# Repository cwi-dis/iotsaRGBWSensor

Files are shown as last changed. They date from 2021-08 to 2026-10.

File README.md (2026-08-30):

# iotsaRGBWSensor




Light sensor that detects RGB, White and ambient light using a VEML6040 color sensor.

Based on [iotsa](https://github.com/cwi-dis/iotsa).

The sensor uses a cheap AliExpress VEML6040 board (you may have to de-solder the white LED if
you want to take emitted/ambient light readings, as opposed to measuring the color of objects).

The VEML6040 is described in <https://www.vishay.com/docs/84276/veml6040.pdf> with additional
design information available at <https://www.vishay.com/docs/84331/designingveml6040.pdf>.

The interface library used is <https://github.com/thewknd/VEML6040>

## Hardware construction

Any esp32 board will do. I have used a lolin 32 lite, because it has a LiPo charger on the board. Here is the breadboard layout:

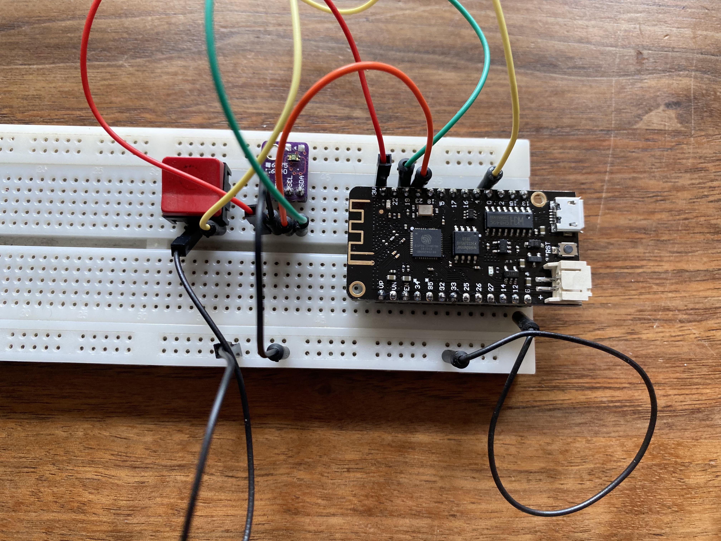
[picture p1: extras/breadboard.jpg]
breadboard layout


Connections to be made:

- GND to VEML GND, pushbutton
- 3V to VEML VCC
- GPIO19 to VEML SDA
- GPIO23 to VEML SCL
- GPIO0 to pushbutton

After the breadboard work I've transferred the components to a solderboard. It's not a work of art, I wanted the sensor on the bottom of the board for easier measurement, but that led to routing problems. But it works:

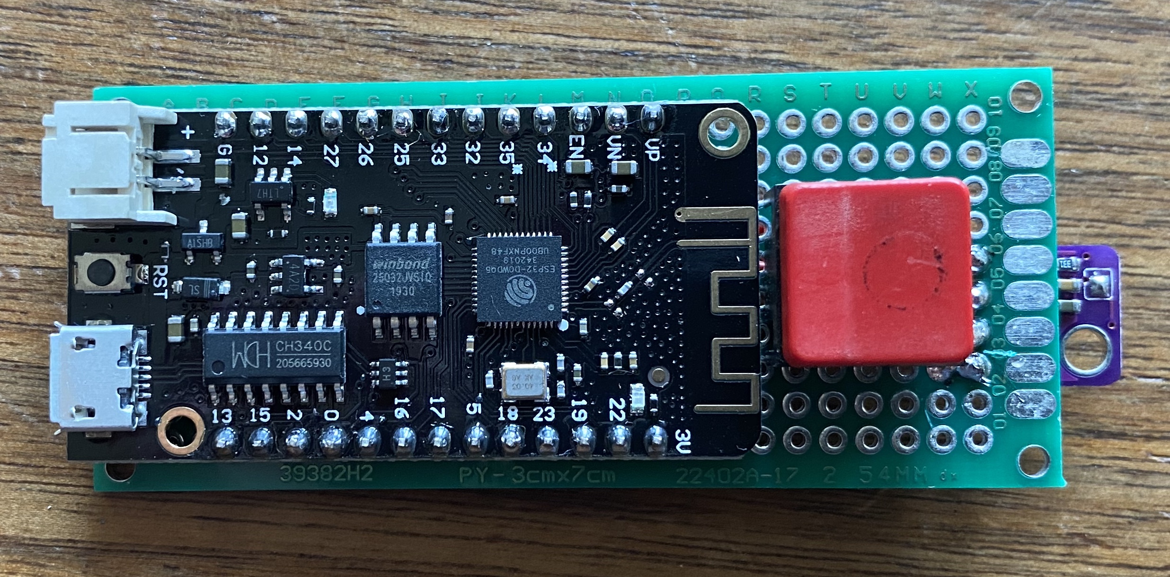
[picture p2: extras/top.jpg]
solderboard top


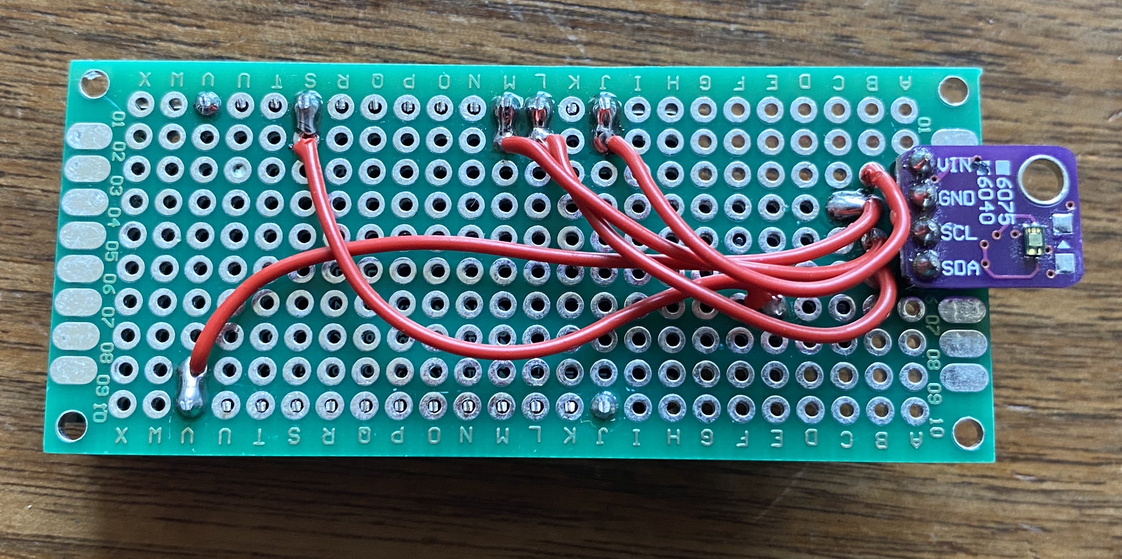
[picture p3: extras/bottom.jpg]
solderboard bottom


See the note above about desoldering the bright white LED on the VEML.

### 3d-printed case

Here are pictures of a 3d-printed case for the board, plus a LiPo battery:

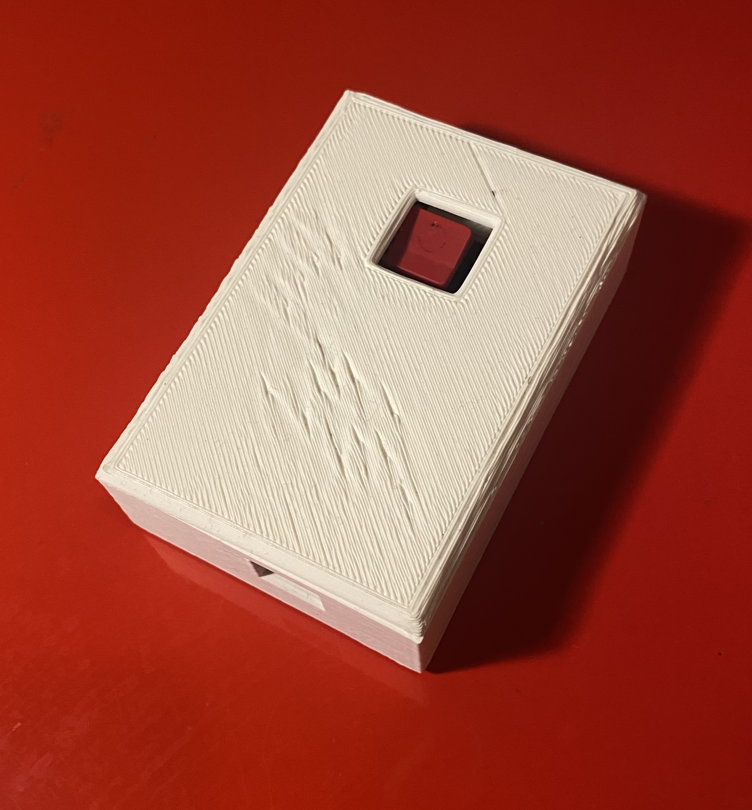
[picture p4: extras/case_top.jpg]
case top


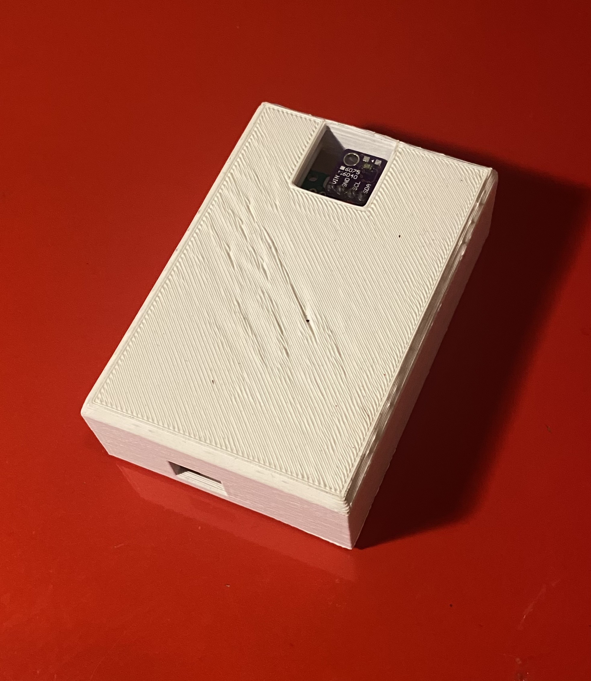
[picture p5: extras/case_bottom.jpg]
case bottom


The `extras` folder contains the `.stl` files to print the box and the lid, and it also has the `colorimeter.f3d` Autodesk Fusion file in case you want to make modifications.

## Software installation

- Build using PlatformIO (`pio run`), or the Arduino IDE / `arduino-cli`.
  - The `build_opt.h` file passes `-DIOTSA_WITH_BLE` to the Arduino build (PlatformIO
    gets it from `platformio.ini`). Don't remove it.
  - In the Arduino IDE, set **Tools → Partition Scheme → Minimal SPIFFS** — the
    BLE firmware does not fit the default partition.
  - Install the required libraries: `VEML6040`, plus everything in iotsa's
    `library.properties` `depends=` (`Adafruit NeoPixel`, `ArduinoJson`,
    `cmArduinoJWT`, `CoAP simple library`, `Ds1302`, `ESP32Encoder`,
    `NimBLE-Arduino`, `esp32_idf5_https_server_compat`). PlatformIO resolves
    these automatically; the Arduino IDE does not when iotsa is a local checkout.
- Flash to the board over USB.
- Board will create a WiFi hotspot `config-xxxxxxx`.
- Connect to that WiFi, browse to <http://192.168.4.1>, configure hostname (lets say `colorsensor` for this example), WiFi SSID and Password. You may have to reset the board to switch to configuration mode, it will tell you.
- Reset the board, it will connect to your wifi with hostname `colorsensor.local`.
- Browse to battery config. Set sleep mode to _Deep Sleep_, wake time to _60000_.

## Usage

Boot the board. If you have set the battery config above the board will go to deep sleep after 60 seconds of inactivity (saving battery). Pressing the button will wake it again, or keep it awake for another 60 seconds. Accessing the web or REST interface will also keep it awake for another 60 seconds.

Point the sensor at whatever light (or lit surface) you want to measure.

Read the results with a browser to <http://colorsensor.local/rgbw> in human-readable form, or <http://colorsensor.local/api/rgbw> as JSON (REST interface).

You can reflash the board over the air, see [iotsa](https://github.com/cwi-dis/iotsa) for details. Tapping the button 3 times will enable OTA mode or config mode (after being requested over the net), tapping it 6 times will force a reboot.

## Python tool

The `extras/python/` directory contains the `colorMeter` Python tool for retrieving, storing, and graphing readings from the device.

### Setup

(If instructions in this repo's parent directory cover venv setup, those take precedence over the steps below.)

From the repo root:

```sh
python3 -m venv .venv
source .venv/bin/activate
pip install -e ../iotsa/extras/python/
pip install -e extras/python/
```

Or, if you have the `requirements_dev.txt`:

```sh
python3 -m venv .venv
source .venv/bin/activate
pip install -r extras/python/requirements_dev.txt
pip install -e extras/python/
```

### Usage

Retrieve current data from a device and print it:

```sh
colorMeter -d colorsensor.local
```

Save readings to a CSV file (repeat to append more readings over time):

```sh
colorMeter -d colorsensor.local -o readings.csv
```

Read back a CSV file and plot the CCT (color temperature) reading on the CIE 1931 chromaticity diagram:

```sh
colorMeter -i readings.csv -g
```

This device is also used by [lissabon](https://github.com/cwi-dis/lissabon)'s `lissabonCalibrate` package to calibrate RGBW ledstrips (it talks to the device's `rgbw` API directly rather than through this tool). `colorMeter` is deliberately kept simpler and free of any lissabon-specific logic, so it stays useful as a general-purpose way to read this sensor — that was already the intent when it was split off in 2021.

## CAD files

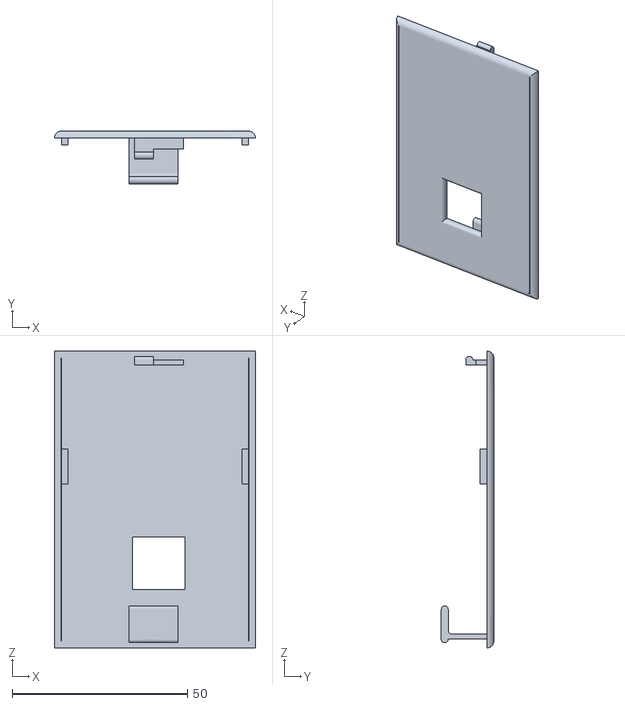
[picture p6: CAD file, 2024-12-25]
extras/colormeter_lid.stl
57.3 x 15.0 x 84.6

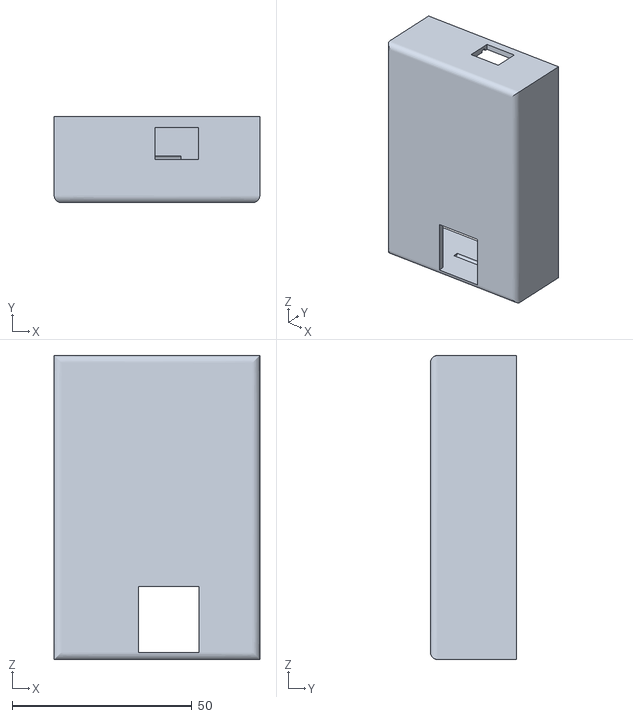
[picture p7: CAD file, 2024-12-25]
extras/colormeter_box.stl
57.3 x 24.0 x 84.7

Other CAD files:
extras/colormeter.f3d

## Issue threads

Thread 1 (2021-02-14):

Fix ci/cd for Arduino

jackjansen, 2021-02-14:
the veml6040 library is now available in the Arduino library manager: https://github.com/thewknd/VEML6040/issues/4

should fix the ci/cd script.

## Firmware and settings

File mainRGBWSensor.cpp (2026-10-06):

//
// RGBW colour / ambient-light sensor (VEML6040) exposed over WiFi (web + REST)
// and BLE. Battery-aware: the wake button on GPIO0 disables deep sleep and
// doubles as the config-mode tap gesture.
//

#include <Arduino.h>
#include "iotsa.h"
#include "iotsaBattery.h"
#include "iotsaInput.h"
#include "iotsaRGBWSensorMod.h"

// Low signal on this pin disables deep sleep; it is also the config-mode
// tap button (see button0Pressed() below).
#define PIN_DISABLE_SLEEP 0

IotsaApplication application("Iotsa RGBWSensor Server");
IotsaBatteryMod batteryMod(application);

Button buttonWake(PIN_DISABLE_SLEEP, true, false, true);
Input *inputs[] = {
  &buttonWake
};
IotsaInputMod inputMod(application, inputs, 1);

IotsaRGBWSensorMod rgbwMod(application);

//
// Keep track of button presses, so we can switch mode or reboot with quick presses.
//
bool button0Pressed() {
  const int TAP_COUNT_MODE_CHANGE=3;
  const int TAP_COUNT_REBOOT=6;
  const uint32_t TAP_DURATION=1000;

  IFDEBUG IotsaSerial.println("button0 pressed");
  iotsaController.extendCurrentMode();
  static uint32_t lastButtonTapMillis = 0;
  static int buttonTapCount = 0;
  uint32_t now = millis();
  if (lastButtonTapMillis > 0 && now < lastButtonTapMillis + TAP_DURATION) {
    // A button change that was quick enough for a tap
    lastButtonTapMillis = now;
    buttonTapCount++;
    if (buttonTapCount == TAP_COUNT_MODE_CHANGE) {
      IFDEBUG IotsaSerial.println("tap mode change");
      iotsaController.allowRequestedConfigurationMode();
    }
    if (buttonTapCount == TAP_COUNT_REBOOT) {
      IFDEBUG IotsaSerial.println("tap mode reboot");
      iotsaController.requestReboot(1000);
    }
  } else {
    // Either the first change, or too late. Reset.
    lastButtonTapMillis = millis();
    buttonTapCount = 0;
  }
  return true;
}

void setup(void){
  application.setup();
  application.lateSetup();
  batteryMod.setPinDisableSleep(PIN_DISABLE_SLEEP);
  buttonWake.setCallback(button0Pressed);
}

void loop(void){
  application.loop();
}

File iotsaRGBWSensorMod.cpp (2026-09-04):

#include "iotsa.h"
#include "iotsaRGBWSensorMod.h"
#include "iotsaConfigFile.h"
#include "Wire.h"
#include "veml6040.h"

VEML6040 sensor;

// VEML6040 I2C pins. App-only, single consumer -- no need for build_opt.h /
// build_flags; override at build time if a board wires it differently.
#ifndef IOTSA_VEML_SDA
#define IOTSA_VEML_SDA 19
#endif
#ifndef IOTSA_VEML_SCL
#define IOTSA_VEML_SCL 23
#endif

void IotsaRGBWSensorMod::configLoad() {
  IotsaConfigFileLoad cf("/config/rgbwsensor.cfg");
  cf.get("integrationInterval", integrationInterval, 320);
  _setInterval();
}

void IotsaRGBWSensorMod::configSave() {
  IotsaConfigFileSave cf("/config/rgbwsensor.cfg");
  cf.put("integrationInterval", integrationInterval);
  _setInterval();
}

void
IotsaRGBWSensorMod::webHandler() {
  iotsaController.extendCurrentMode();
  bool anyChanged = false;
  if( api.webService->server->hasArg("integrationInterval")) {
    if (needsAuthentication()) return;
    String sInterval = api.webService->server->arg("integrationInterval");
    integrationInterval = sInterval.toInt();
    anyChanged = true;
  }
  if (anyChanged) configSave();
  String message = "<html><head><title>RGBW sensor module</title></head><body><h1>RGBW sensor module</h1>";
  _measure();
  if (error) {
    message += "<p><em>Error: VEML6040 sensor not detected</em></p>";
  }
  message += "<h2>Sensor Configuration</h2>";
  message += "<form method='get'>Integration interval (ms): <input name='integrationInterval' value='";
  message += String(integrationInterval);
  message += "'><input type='submit' value='Configure'></form>";
  message += "<h2>Sensor Reading</h2>";
  message += "<form method='get'><input type='submit' value='Refresh'></form>";

  if (r > 0.99 || g > 0.99 || b > 0.99) {
    message += "<p><em>Note:</em> Color channel over-exposed, decrease interval for better color results.</p>";
  } else
  if (r < 0.33 && g < 0.33 && b < 0.33) {
    message += "<p><em>Note:</em> Increasing interval may give better color results.</p>";
  } else
  if (w > 0.99) {
    message += "<p><em>Note:</em> W channel over-exposed. May mean lots of IR light.</p>";
  }

  message += "<p>RGBW counts: R=" + String(raw_r) + ", G=" + String(raw_g) + ", B=" + String(raw_b) + ", W=" + String(raw_w) + "<br>";
  message += "RGB intensities: R=" + String(r) + ", G=" + String(g) + ", B=" + String(b) + "<br>";
  uint32_t hexColor = ((int)(r*255) << 16) | ((int)(g*255) << 8) | ((int)(b*255));
  
  message += "Color 0x" + String(hexColor, 16)+ ": <svg width='40' height='40'><rect width='40' height='40' style='fill:#" + String(hexColor, HEX) + ";stroke-width:2;stroke:rgb(0,0,0)' /></svg>";
  float maxRGB = max(r, max(g, b));
  if (maxRGB == 0) maxRGB = 1;
  hexColor = ((int)(r/maxRGB*255) << 16) | ((int)(g/maxRGB*255) << 8) | ((int)(b/maxRGB*255));
  message += "Hue 0x" + String(hexColor, 16) + ": <svg width='40' height='40'><rect width='40' height='40' style='fill:#" + String(hexColor, HEX) + ";stroke-width:2;stroke:rgb(0,0,0)' /></svg><br>";

  message += "White intensity: W=" + String(w) + "<br>";
  message += "Color temperature: CCT=" + String(cct) + "<br>";
  message += "Ambient light level: " + String(lux) + "lux<br>";
  message += "(Integration interval: "+ String(integrationInterval) + "ms)";
  api.webService->server->send(200, "text/html", message);
}

String IotsaRGBWSensorMod::info() {
  iotsaController.extendCurrentMode();
  String message = "<p>Built with RGBW sensor module. See <a href=\"/rgbw\">/rgbw</a>, or <a href=\"/api/rgbw\">/api/rgbw</a> for REST API.</p>";
  return message;
}

void IotsaRGBWSensorMod::setup() {
  Wire.begin(IOTSA_VEML_SDA, IOTSA_VEML_SCL);
  if(sensor.begin()) {
    configLoad();
    error = false;
    IFDEBUG IotsaSerial.println("VEML6040 sensor attached");
  } else {
    error = true;
    IFDEBUG IotsaSerial.println("VEML6040 sensor not found");
  }
}

void IotsaRGBWSensorMod::_setInterval() {
  uint8_t conf;
  if (integrationInterval <= 40) {
    integrationInterval = 40;
    conf = VEML6040_IT_40MS + VEML6040_AF_AUTO + VEML6040_SD_ENABLE;
  } else
  if (integrationInterval <= 80) {
    integrationInterval = 80;
    conf = VEML6040_IT_80MS + VEML6040_AF_AUTO + VEML6040_SD_ENABLE;
  } else
  if (integrationInterval <= 160) {
    integrationInterval = 160;
    conf = VEML6040_IT_160MS + VEML6040_AF_AUTO + VEML6040_SD_ENABLE;
  } else
  if (integrationInterval <= 320) {
    integrationInterval = 320;
    conf = VEML6040_IT_320MS + VEML6040_AF_AUTO + VEML6040_SD_ENABLE;
  } else
  if (integrationInterval <= 640) {
    integrationInterval = 640;
    conf = VEML6040_IT_640MS + VEML6040_AF_AUTO + VEML6040_SD_ENABLE;
  } else {
    integrationInterval = 1280;
    conf = VEML6040_IT_1280MS + VEML6040_AF_AUTO + VEML6040_SD_ENABLE;
  }
  sensor.setConfiguration(conf);
  nextReadingAvailable = millis() + oldIntegrationInterval + integrationInterval + 1;
  oldIntegrationInterval = integrationInterval;
}

bool IotsaRGBWSensorMod::getHandler(const char *path, JsonObject& reply) {
  iotsaController.extendCurrentMode();
  _measure();
  if (error) {
    reply["error"] = "no sensor";
    return true;
  }
  reply["raw_r"] = raw_r;
  reply["raw_g"] = raw_g;
  reply["raw_b"] = raw_b;
  reply["raw_w"] = raw_w;
  reply["r"] = r;
  reply["g"] = g;
  reply["b"] = b;
  reply["w"] = w;
  reply["cct"] = cct;
  reply["lux"] = lux;
  reply["integrationInterval"] = integrationInterval;
  return true;
}

bool IotsaRGBWSensorMod::putHandler(const char *path, const JsonVariant& request, JsonObject& reply) {
  iotsaController.extendCurrentMode();
  bool anyChanged = false;
  JsonObject reqObj = request.as<JsonObject>();
  if (getFromRequest<int>(reqObj, "integrationInterval", integrationInterval)) {
    anyChanged = true;
  }
  if (anyChanged) configSave();
  return anyChanged;
}

void IotsaRGBWSensorMod::lateSetup() {
  name = "rgbw";
  api.setup("rgbw", true, true);
}

void IotsaRGBWSensorMod::_measure() {
  if (error) return;
  uint32_t now = millis();
  if (now < nextReadingAvailable) delay(nextReadingAvailable-now);
  raw_r = sensor.getRed();
  raw_g = sensor.getGreen();
  raw_b = sensor.getBlue();
  raw_w = sensor.getWhite();
  r = (float)raw_r/raw_w;
  g = (float)raw_g/raw_w;
  b = (float)raw_b/raw_w;
  w = (float)raw_w/65536.0;
  cct = (float)sensor.getCCT();
  lux = sensor.getAmbientLight();
  nextReadingAvailable = millis() + integrationInterval;
  IFDEBUG IotsaSerial.printf("raw_r=%d raw_g=%d raw_b=%d raw_w=%d r=%f g=%f b=%f w=%f cct=%f lux=%f\n", raw_r, raw_g, raw_b, raw_w, r, g, b, w, cct, lux);
}

void IotsaRGBWSensorMod::loop() {
}

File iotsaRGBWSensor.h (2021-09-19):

#ifndef _IOTSARGBWSENSOR_H_
#define _IOTSARGBWSENSOR_H_
#include "iotsa.h"
#include "iotsaApi.h"

#ifdef IOTSA_WITH_API
#define IotsaRGBWSensorModBaseMod IotsaApiMod
#else
#define IotsaRGBWSensorModBaseMod IotsaMod
#endif

class IotsaRGBWSensorMod : public IotsaRGBWSensorModBaseMod {
public:
  using IotsaRGBWSensorModBaseMod::IotsaRGBWSensorModBaseMod;
  void setup() override;
  void serverSetup() override;
  void loop() override;
  String info() override;
  void configLoad() override;
  void configSave() override;
protected:
  bool getHandler(const char *path, JsonObject& reply) override;
  bool putHandler(const char *path, const JsonVariant& request, JsonObject& reply) override;
  void handler();
  void _measure();
  void _setInterval();
  bool error;
  int raw_r;
  int raw_g;
  int raw_b;
  int raw_w;
  float r;
  float g;
  float b;
  float w;
  float cct;
  float lux;
  uint32_t integrationInterval = 320;
  uint32_t oldIntegrationInterval = 320;
  uint32_t nextReadingAvailable = 0;
};

#endif

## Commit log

2020-09-26 Add aibility to wake on button 0.
2021-01-03 Build all iotsa products for at least nodemcuv2 and esp32thing
2021-01-03 Use board_build.ldscript
2021-08-20 Adopted for lolin32lite board, use GPIO 19 and 23 for 2wire protocol
2021-08-20 Extend current mode on incoming requests, so we can use deep sleep with 60s wake time to save battery
2021-08-20 Added reboot/config mode switching with button taps
2021-08-20 Added instructions on building the hardware and configuring/using the board
2021-08-26 Print values read
2021-09-18 Also report raw RGBW sensor counts
2021-09-19 integrationInterval was basically ignored. Fixed. Also saved to config file.
    [iotsaRGBWSensor.cpp, iotsaRGBWSensor.h]
2021-09-19 Attempting to fix intensities by doing relative to raw W. Unsure it is a good idea.
    [iotsaRGBWSensor.cpp]
2023-09-09 Getting started with plotting color temperature values
2024-12-25 Added 3d-printed case.
    [colormeter.f3d, colormeter_box.stl, colormeter_lid.stl]
2024-12-25 Oops, missed removal of one line.
    [iotsaRGBWSensor.cpp]
2025-04-27 Updated arduino build job
2025-04-27 Renaming, so it becomes compatible with Arduino IDE.
2025-04-27 Library is available in the arduino library manager nowadays.
2026-08-12 Use cmArduinoJWT fork instead of unmaintained ArduinoJWT
    Fixes cwi-dis/iotsa#184
2026-08-13 Replace fork --git-url installs with Library Manager references in Arduino CI
    cmArduinoJWT and esp32_idf5_https_server_compat are now published in the
    Arduino Library Manager, so the arduino-cli workflow no longer needs
    --git-url installs for them (esp32_idf5_https_server resolves
    transitively via esp32_idf5_https_server_compat's own depends=). iotsa
    itself is still installed via --git-url, pinned to the branch/ref under
    test.
    cwi-dis/iotsa#96
2026-08-13 arduino-cli: force a fresh library index before name-based lib installs
    The previous commit switched cmArduinoJWT and esp32_idf5_https_server_compat
    from --git-url installs to name-based Library Manager lookups. That exposed
    a latent bug in the "Cache Arduino CLI" step: its cache key hashes
    *_index.json in the repo working directory, which doesn't exist here, so
    the key is effectively static and a cache-hit silently restores whatever
    library_index.json was saved on the very first run -- forever, since
    arduino-cli only auto-downloads that index when it's completely absent,
    never when it's merely stale.
    Confirmed locally (with arduino-cli installed via brew): installing
    cmArduinoJWT against a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
2026-08-14 ci: bump GitHub Actions to current majors (checkout@v7, setup-python@v7, upload-artifact@v7, cache@v6)
    These were pinned to versions from 2020-2021 (checkout@v2, setup-python@v2 -
    both Node16, upload-artifact@v4, cache@v2), well past their supported
    window. Matches the versions already verified working in iotsa itself.
2026-08-30 Migrate to iotsa v3 API + vendor board definitions
    v3 API (cwi-dis/iotsa#199):
    - IotsaRGBWSensorMod: drop the IotsaApiMod/IotsaMod macro dance -> derive
    from IotsaModule directly; serverSetup() -> lateSetup(); handler() ->
    webHandler() override; server-> -> api.webService->server->;
    api.setup("/api/rgbw", ...) -> api.setup("rgbw", ...) (the /rgbw page is
    auto-registered now); name = "rgbw" set in lateSetup().
    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
2026-08-30 #149: move app glue into mainRGBWSensor.cpp, flatten WITH_* scaffolding
    The .ino is now just #include <iotsa.h> (Arduino-IDE compatibility);
    all glue -- defines, module instantiation, button0Pressed() tap gesture,
    setup()/loop() -- moves to mainRGBWSensor.cpp.
    Flattened while moving:
    - Dropped the #undef WITH_USER/WITH_NTP/WITH_FILES* lines (nothing defines
    them) and the #ifdef WITH_OTA / #ifdef WITH_BATTERY / #ifdef
    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
2026-08-30 Fix the Arduino build: -DIOTSA_WITH_BLE via build_opt.h
    The v3 migration stripped the #ifdef IOTSA_WITH_BLE guard around bleserverMod
    but IOTSA_WITH_BLE is off by default in iotsa and was only ever set via
    platformio.ini build_flags -- which the Arduino IDE / arduino-cli build does
    not see. Worse, the flag has to reach iotsa's *own* iotsaBLEServer.cpp (it
    gates the vtable), so a #define in app source can't fix it either.
    build_opt.h is read by the Arduino build and applied to sketch + core +
    libraries, so a one-line `-DIOTSA_WITH_BLE` there makes iotsa's BLE code
    compile. PlatformIO ignores build_opt.h and keeps the same flag in
    build_flags; the two are mirrors, kept in sync by comment.
    -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
    [iotsaRGBWSensorMod.cpp]
2026-08-30 build-arduino: install NimBLE-Arduino
    Now that the Arduino build has -DIOTSA_WITH_BLE (via build_opt.h), iotsa's
    iotsaBLEServer.cpp pulls <NimBLEDevice.h>. NimBLE-Arduino is in iotsa's
    library.properties depends= but the workflow never installed it -- the old
    esp8266 Arduino build had no BLE so it never came up.
    Also note the full library set in the README for Arduino-IDE-from-clone.
2026-08-31 board-defs: re-vendor from iotsa v3.0a2 (drop #228 local patch)
    Re-vendor iotsa-board-defs.ini verbatim from iotsa v3.0a2. The LOCAL
    PATCH pointing [lolin32] at lolin32_lite is now upstream (cwi-dis/iotsa#228),
    so the vendored copy needs no local edits. Also picks up the new
    [lolin32_oled] section (cwi-dis/iotsa#229) and the completed [crowpanel128]
    partition/flash fields (cwi-dis/iotsa#226). No effect on this repo's build.
    Claude-Session: https://claude.ai/code/session_01JK4ha63zeEirSaBRkjhC4p
2026-09-04 Migrate mode/reboot calls to iotsaController.* (cwi-dis/iotsa#243)
    The iotsaConfig.* mode/reboot forwarders were removed in cwi-dis/iotsa#243
    (#106 kept them one release). Literal renames, behaviour-identical:
    - iotsaRGBWSensorMod.cpp: extendCurrentMode() x4 (web/info/get/put handlers)
    - mainRGBWSensor.cpp: extendCurrentMode() (button0), allowRequestedConfigurationMode(),
    requestReboot(1000) (tap gestures)
    Not revisited here: whether the read-only handlers (info/getHandler) should
    use noteActivity() instead of extendCurrentMode() (a read arguably shouldn't
    push out a maintenance-mode auto-expiry) -- iotsa#106 nuance, left for review.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
    [iotsaRGBWSensorMod.cpp, mainRGBWSensor.cpp]
2026-10-05 Re-vendor iotsa board definitions; drop redundant min_spiffs.csv lines
    Refreshes iotsa-board-traits.ini / iotsa-board-defs.ini from iotsa
    develop (last vendored 2026-08-31). Picks up:
    - espressif32 platform pinned to 7.1.3 (cwi-dis/iotsa#269)
    - board_build.filesystem = littlefs, so `pio run -t uploadfs` builds an
    image the firmware can mount (cwi-dis/iotsa#269)
    - min_spiffs.csv as the default partition layout for all 4MB ESP32
    boards (cwi-dis/iotsa#245), making local board_build.partitions =
    min_spiffs.csv lines redundant -- removed where present
    - the NimBLE host-task stack flag for all ESP32 builds (cwi-dis/iotsa#127)
    Resolved config checked before/after with `pio project config`: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
2026-10-06 Adapt to iotsa's standard modules and per-application authenticator
    Re-vendor iotsa-board-traits.ini / iotsa-board-defs.ini from iotsa
    develop (status LED defines: IOTSA_PIN_LED, IOTSA_LED_NEOPIXEL,
    IOTSA_LED_ACTIVE_LOW).
    - Drop the IotsaWifiMod/IotsaOtaMod declarations: iotsa now creates the
    WiFi and OTA modules automatically (cwi-dis/iotsa#85).
    - Drop the IotsaBLEServerMod declaration: created automatically in BLE
    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
